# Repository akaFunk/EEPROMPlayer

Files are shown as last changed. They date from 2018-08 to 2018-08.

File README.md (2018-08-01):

# EEPROMPlayer
The EEPROMPlayer is an audio player that can play audio from an (E)EPROM using no microcontroller, but only simple logic ICs and an analog audio amplifier.

The EPROM used is compatible to standard 27C010 EPROMs. The clock is generated using an NE555 timer and then diveded several times using 74LS74 flip-flops. Each clock signal is fed to one of the address lines of the EPROM. The EPROM holds the raw audio data in 8 bit. The 8 data lines are passed into an R2R-network which does the digital to analog conversion. An LM386 is used to amplify the signal.

## Images
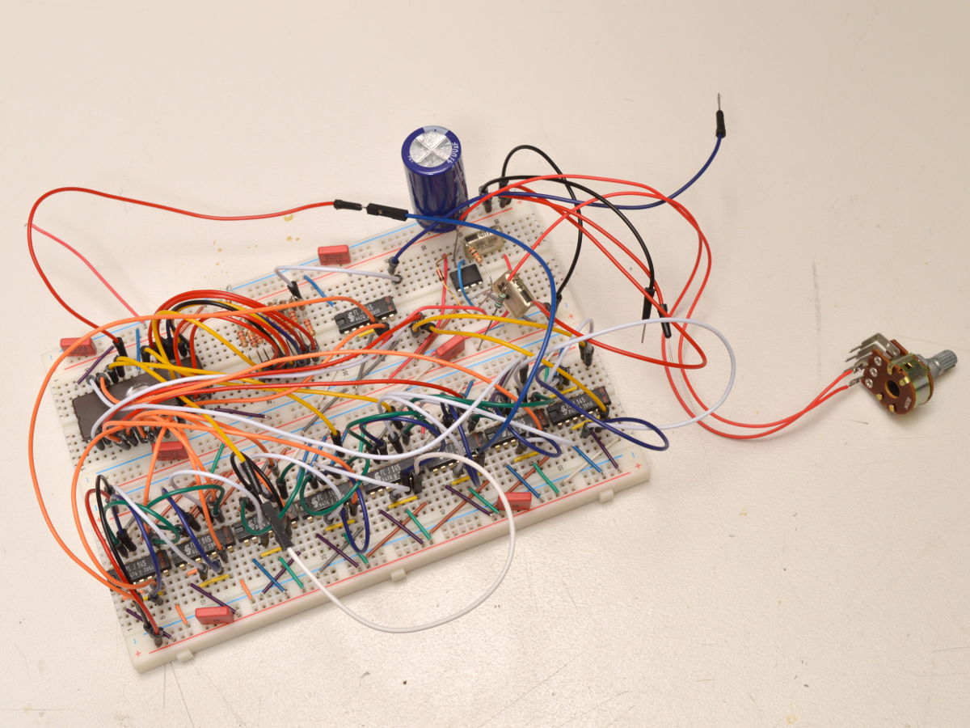
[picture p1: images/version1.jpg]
Version 1 using a breadboard

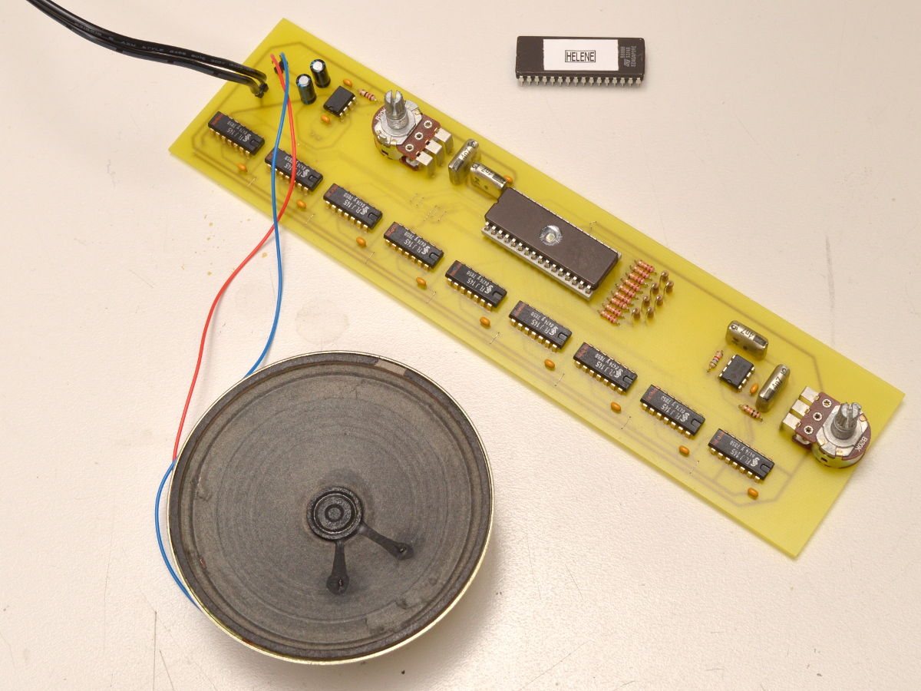
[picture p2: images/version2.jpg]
Version 2 using a milled PCB


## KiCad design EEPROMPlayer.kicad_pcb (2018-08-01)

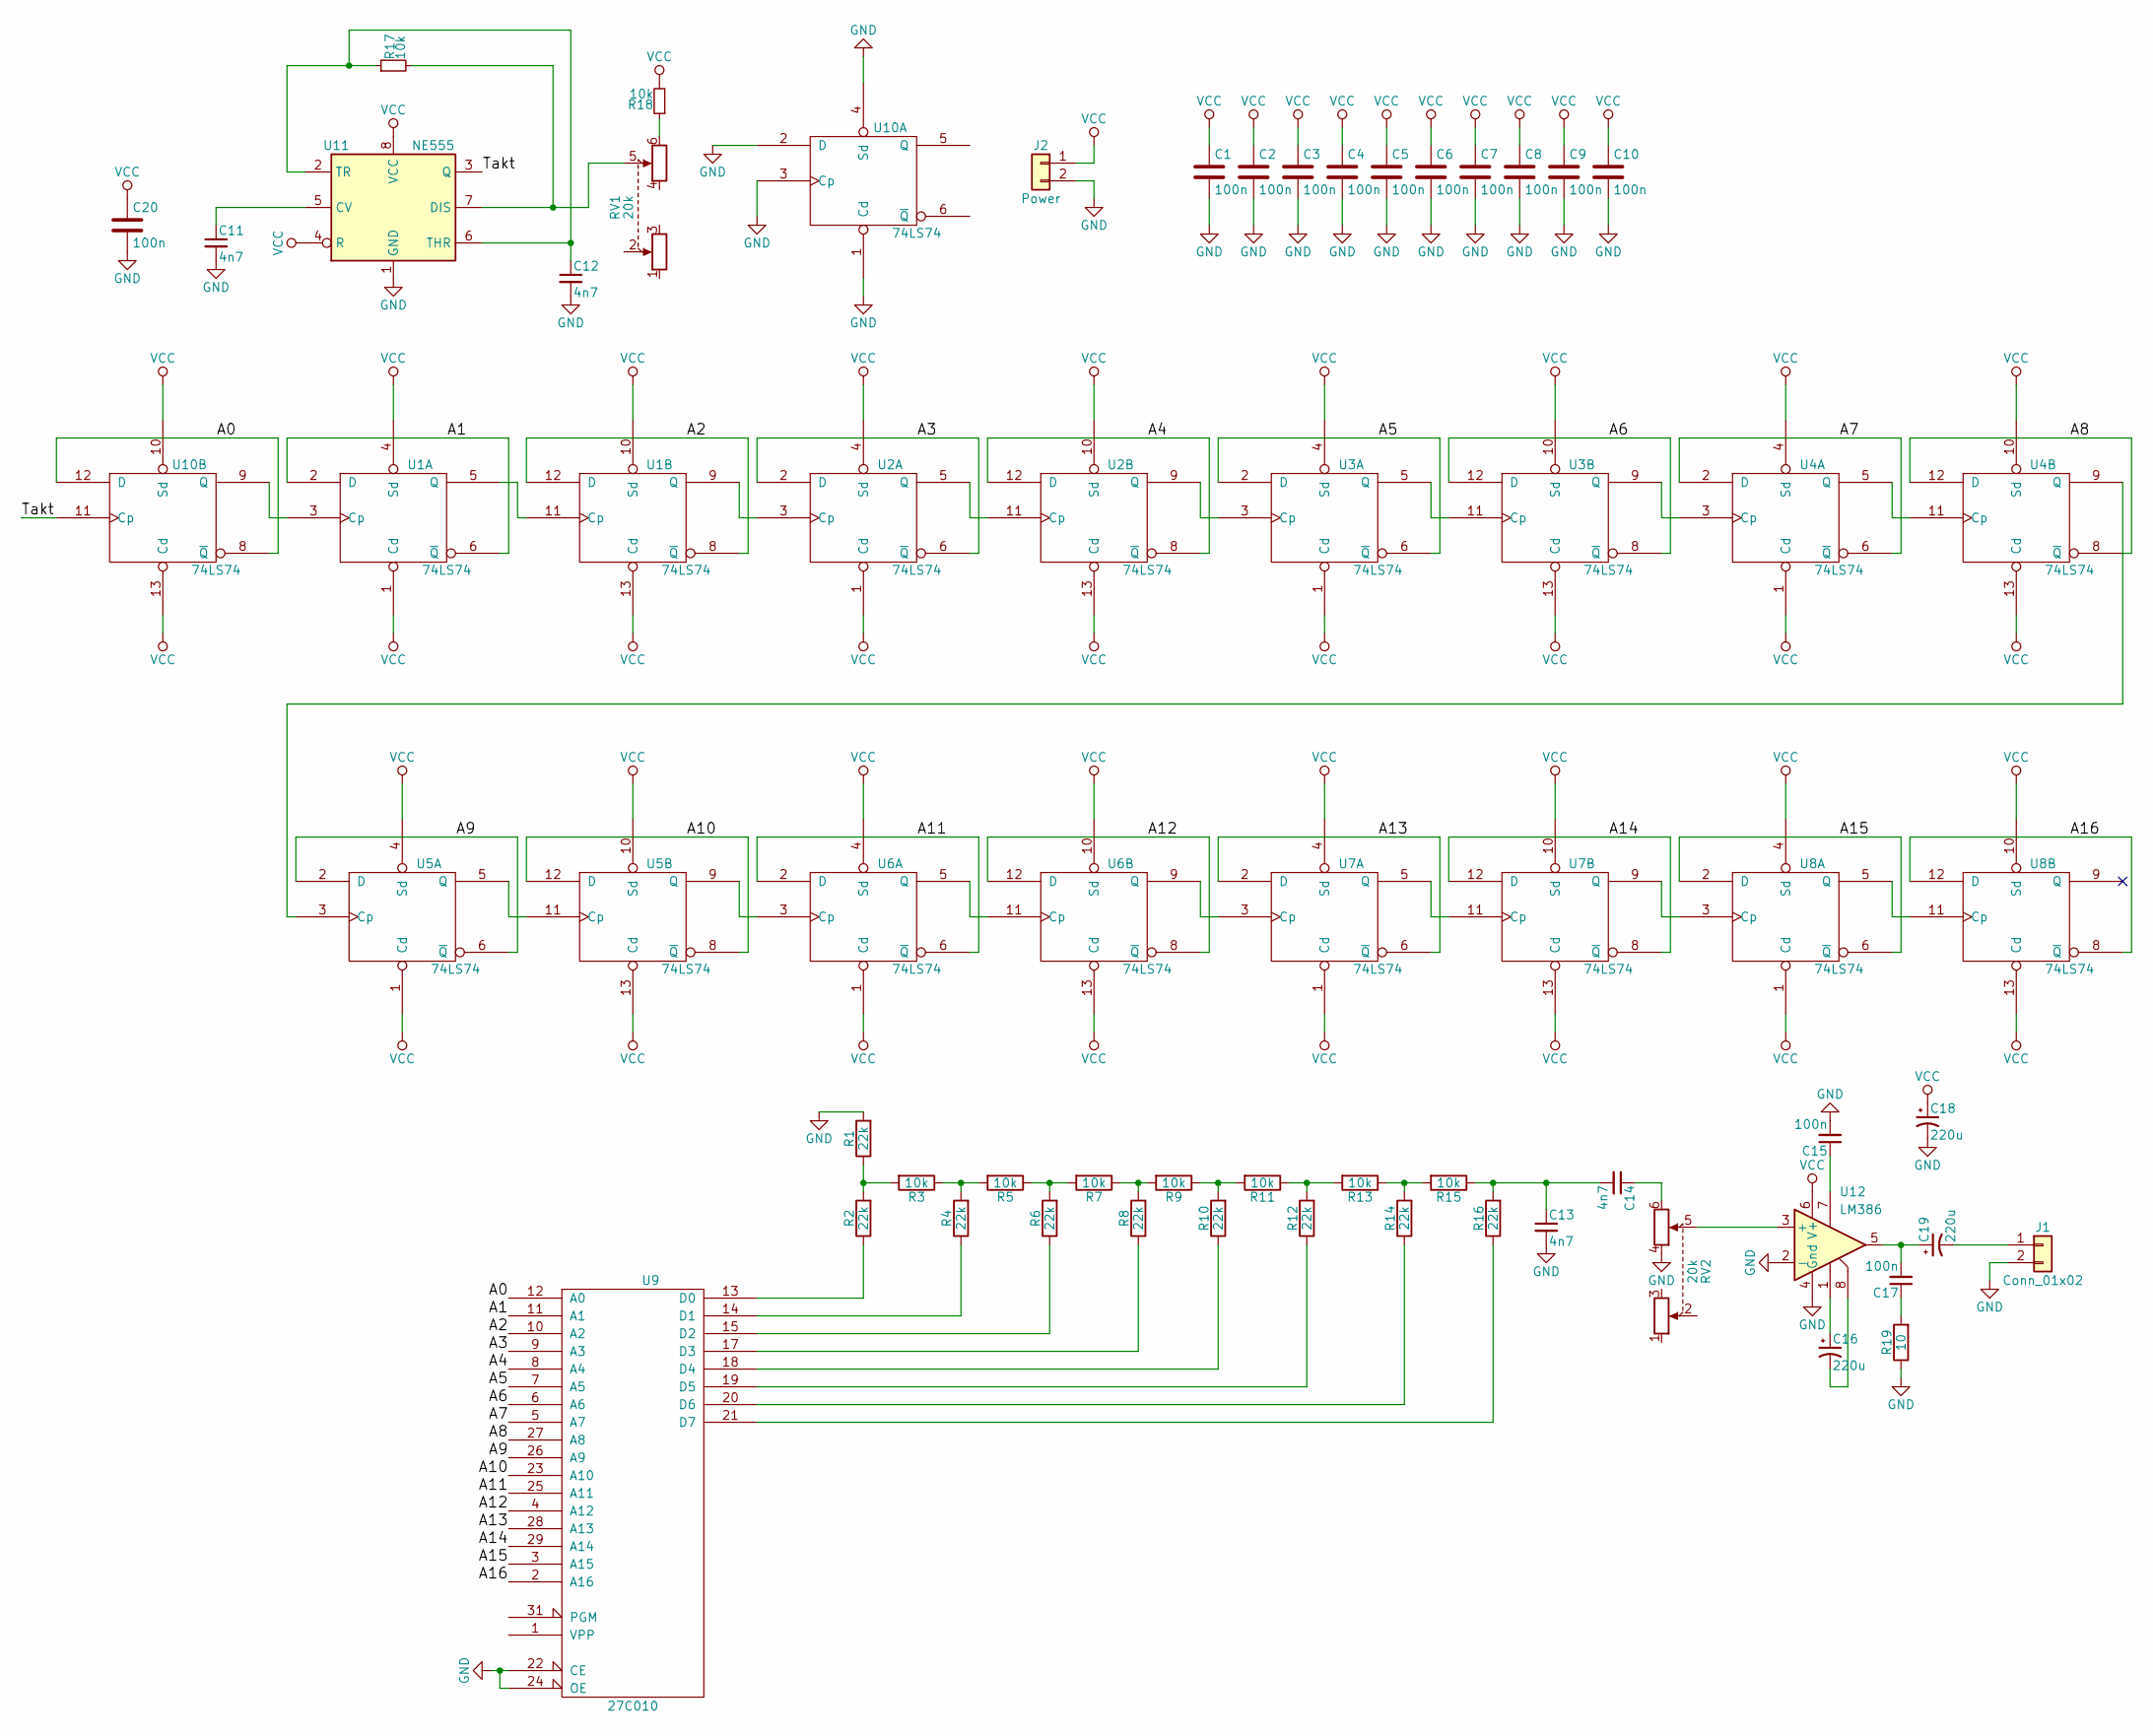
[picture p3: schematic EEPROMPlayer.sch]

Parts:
C1, C2, C3, C4, C5, C6, C7, C8, C9, C10, C15, C17, C20: 100n; C_Disc_D3.0mm_W1.6mm_P2.50mm
C11, C12, C13, C14: 4n7; C_Disc_D12.5mm_W5.0mm_P10.00mm
C16, C18, C19: 220u; CP_Radial_D6.3mm_P2.50mm
J1: Conn_01x02; Pin_Header_Straight_1x02_Pitch2.54mm
J2: Power; Pin_Header_Straight_1x02_Pitch2.54mm
R1, R2, R4, R6, R8, R10, R12, R14, R16: 22k; R_Axial_DIN0204_L3.6mm_D1.6mm_P7.62mm_Horizontal
R3, R5, R7, R9, R11, R13, R15: 10k; R_Axial_DIN0204_L3.6mm_D1.6mm_P2.54mm_Vertical
R17, R18: 10k; R_Axial_DIN0204_L3.6mm_D1.6mm_P7.62mm_Horizontal
R19: 10; R_Axial_DIN0204_L3.6mm_D1.6mm_P7.62mm_Horizontal
RV1, RV2: 20k; Potentiometer_Alps_RK163_Double_Vertical
U1, U2, U3, U4, U5, U6, U7, U8, U10: 74LS74; DIP-14_W7.62mm_LongPads
U9: 27C010; DIP-32_W15.24mm_LongPads
U11: NE555; DIP-8_W7.62mm_LongPads
U12: LM386; DIP-8_W7.62mm_LongPads

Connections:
/A0: U9.12 (A0), U10.8 (~Q), U10.12 (D)
/A1: U1.2 (D), U1.6 (~Q), U9.11 (A1)
/A2: U1.8 (~Q), U1.12 (D), U9.10 (A2)
/A3: U2.2 (D), U2.6 (~Q), U9.9 (A3)
/A4: U2.8 (~Q), U2.12 (D), U9.8 (A4)
/A5: U3.2 (D), U3.6 (~Q), U9.7 (A5)
/A6: U3.8 (~Q), U3.12 (D), U9.6 (A6)
/A7: U4.2 (D), U4.6 (~Q), U9.5 (A7)
/A8: U4.8 (~Q), U4.12 (D), U9.27 (A8)
/A9: U5.2 (D), U5.6 (~Q), U9.26 (A9)
/A10: U5.8 (~Q), U5.12 (D), U9.23 (A10)
/A11: U6.2 (D), U6.6 (~Q), U9.25 (A11)
/A12: U6.8 (~Q), U6.12 (D), U9.4 (A12)
/A13: U7.2 (D), U7.6 (~Q), U9.28 (A13)
/A14: U7.8 (~Q), U7.12 (D), U9.29 (A14)
/A15: U8.2 (D), U8.6 (~Q), U9.3 (A15)
/A16: U8.8 (~Q), U8.12 (D), U9.2 (A16)
/Takt: U10.11 (Cp), U11.3 (Q)
GND: C1.2, C2.2, C3.2, C4.2, C5.2, C6.2, C7.2, C8.2, C9.2, C10.2, C11.2, C12.2, C13.2, C15.2, C18.2, C20.2, J1.2, J2.2, R1.2, R19.1, RV2.4, U1.7 (GND), U2.7 (GND), U3.7 (GND), U4.7 (GND), U5.7 (GND), U6.7 (GND), U7.7 (GND), U8.7 (GND), U9.16 (GND), U9.22 (CE), U9.24 (OE), U10.1 (Cd), U10.2 (D), U10.3 (Cp), U10.4 (Sd), U10.7 (GND), U11.1 (GND), U12.2 (-), U12.4 (Gnd)
unnamed: C11.1, U11.5 (CV)
unnamed: C12.1, R17.1, U11.2 (TR), U11.6 (THR)
unnamed: C13.1, C14.2, R15.1, R16.2
unnamed: C14.1, RV2.6
unnamed: C15.1, U12.7
unnamed: C16.1, U12.1
unnamed: C16.2, U12.8
unnamed: C17.1, R19.2
unnamed: C17.2, C19.1, U12.5
unnamed: C19.2, J1.1
unnamed: R1.1, R2.2, R3.2
unnamed: R2.1, U9.13 (D0)
unnamed: R3.1, R4.2, R5.2
unnamed: R4.1, U9.14 (D1)
unnamed: R5.1, R6.2, R7.2
unnamed: R6.1, U9.15 (D2)
unnamed: R7.1, R8.2, R9.2
unnamed: R8.1, U9.17 (D3)
unnamed: R10.1, U9.18 (D4)
unnamed: R9.1, R10.2, R11.2
unnamed: R11.1, R12.2, R13.2
unnamed: R12.1, U9.19 (D5)
unnamed: R13.1, R14.2, R15.2
unnamed: R14.1, U9.20 (D6)
unnamed: R16.1, U9.21 (D7)
unnamed: R17.2, RV1.5, U11.7 (DIS)
unnamed: R18.1, RV1.6
unnamed: RV2.5, U12.3 (+)
unnamed: U1.3 (Cp), U10.9 (Q)
unnamed: U1.9 (Q), U2.3 (Cp)
unnamed: U1.5 (Q), U1.11 (Cp)
unnamed: U2.9 (Q), U3.3 (Cp)
unnamed: U2.5 (Q), U2.11 (Cp)
unnamed: U3.9 (Q), U4.3 (Cp)
unnamed: U3.5 (Q), U3.11 (Cp)
unnamed: U4.9 (Q), U5.3 (Cp)
unnamed: U4.5 (Q), U4.11 (Cp)
unnamed: U5.9 (Q), U6.3 (Cp)
unnamed: U5.5 (Q), U5.11 (Cp)
unnamed: U6.9 (Q), U7.3 (Cp)
unnamed: U6.5 (Q), U6.11 (Cp)
unnamed: U7.9 (Q), U8.3 (Cp)
unnamed: U7.5 (Q), U7.11 (Cp)
unnamed: U8.5 (Q), U8.11 (Cp)
VCC: C1.1, C2.1, C3.1, C4.1, C5.1, C6.1, C7.1, C8.1, C9.1, C10.1, C18.1, C20.1, J2.1, R18.2, U1.1 (Cd), U1.4 (Sd), U1.10 (Sd), U1.13 (Cd), U1.14 (VCC), U2.1 (Cd), U2.4 (Sd), U2.10 (Sd), U2.13 (Cd), U2.14 (VCC), U3.1 (Cd), U3.4 (Sd), U3.10 (Sd), U3.13 (Cd), U3.14 (VCC), U4.1 (Cd), U4.4 (Sd), U4.10 (Sd), U4.13 (Cd), U4.14 (VCC), U5.1 (Cd), U5.4 (Sd), U5.10 (Sd), U5.13 (Cd), U5.14 (VCC), U6.1 (Cd), U6.4 (Sd), U6.10 (Sd), U6.13 (Cd), U6.14 (VCC), U7.1 (Cd), U7.4 (Sd), U7.10 (Sd), U7.13 (Cd), U7.14 (VCC), U8.1 (Cd), U8.4 (Sd), U8.10 (Sd), U8.13 (Cd), U8.14 (VCC), U9.32 (VCC), U10.10 (Sd), U10.13 (Cd), U10.14 (VCC), U11.4 (R), U11.8 (VCC), U12.6 (V+)

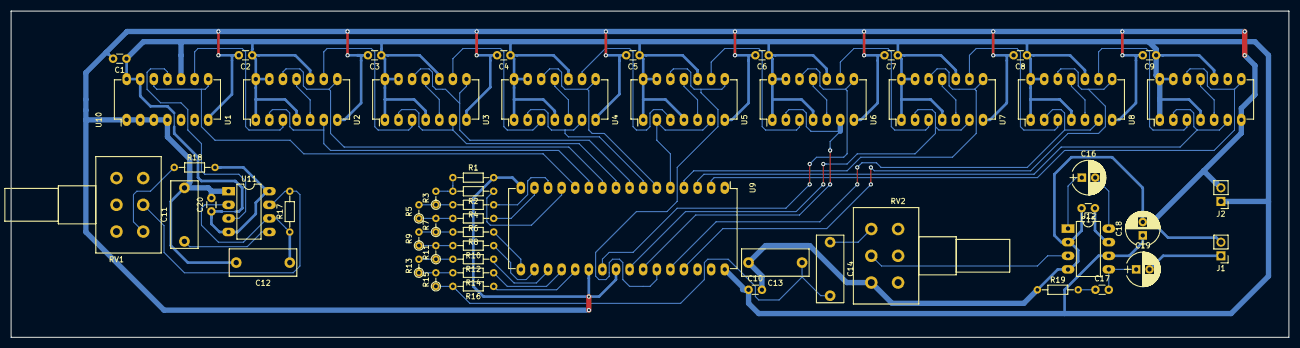
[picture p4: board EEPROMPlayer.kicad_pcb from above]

Board: 2 copper layers, 238.8 x 61.0 mm, 55 parts (0 on the bottom side), 64 nets.

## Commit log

2018-08-01 Updated wrong file names in the files
    [EEPROMPlayer.kicad_pcb, EEPROMPlayer.sch]
2018-08-01 Added gerber files
    [EEPROMT-B.Cu.gbr, EEPROMT-Edge.Cuts.gbr, EEPROMT-F.Cu.gbr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]
2018-08-01 Removed wrong files
    [EEPROMTPlayer.kicad_pcb, EEPROMTPlayer.sch]
